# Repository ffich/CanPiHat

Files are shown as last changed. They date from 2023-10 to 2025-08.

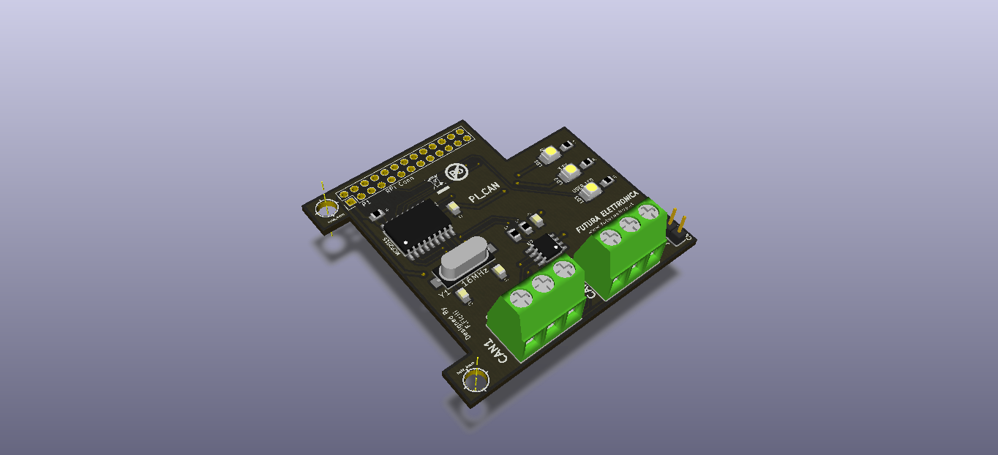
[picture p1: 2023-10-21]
50_3D/CanPi.png

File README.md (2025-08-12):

# 🐍🔌 CanPiHat — CAN Bus HAT for Raspberry Pi

A rugged **CAN-Bus HAT** for the **Raspberry Pi**, powered by the **Microchip MCP2515** CAN controller 🧠 and **MCP2551** high-speed transceiver. Perfect for automotive 🚗, industrial 🏭, and robotics 🤖 CAN applications.

---

## 📡 What is CAN Bus?

**CAN (Controller Area Network)** is a **robust, differential two-wire protocol** designed for reliable, real-time communication between multiple devices (ECUs).  

### ✨ Why CAN is Awesome:
- 🛡 **Reliable** — Automatic error detection, re-transmission & priority handling  
- 📏 **Efficient** — Reduces wiring complexity with a single shared bus  
- 🌍 **Versatile** — Used in cars 🚗, factories 🏭, robots 🤖, and building automation 🏢  

---

## 🛠 Features of CanPiHat

| Icon | Feature |
|---|---|
| 🧠 | **MCP2515** — Stand-alone CAN 2.0B controller with SPI interface (up to 1 Mbps) |
| ⚡ | **MCP2551** — High-speed CAN transceiver for physical layer communication |
| 🍓 | **Pi HAT Form Factor** — Plugs directly into Raspberry Pi’s 40-pin header |
| 🔌 | **Plug & Play** — Just enable SPI and start sending/receiving CAN frames |



---

## 🚀 Why You’ll Love It

- 🛠 **Simple Setup** — Minimal wiring, quick configuration  
- 🎯 **Proven Hardware** — Trusted Microchip CAN ICs  
- 🔄 **Flexible Applications** — From OBD2 logging to factory automation  
- 📡 **SocketCAN Compatible** — Works with `can-utils` and Python CAN libraries  

---

## ⚙ Getting Started

1. 🍓 **Stack** the HAT onto your Raspberry Pi  
2. 🔌 **Connect** CAN_H & CAN_L to your network  
3. 🖥 **Enable** SPI via `raspi-config`  
4. 📦 **Install** can-utils:  
  `sudo apt install can-utils`
5. ⚡ Bring up the CAN interface:
  `sudo ip link set can0 up type can bitrate 500000`
7. 📡 Communicate:
  `cansend can0 123#DEADBEEF`
  `candump can0`

---

## 💡 Applications
Area	Examples
🚗 Automotive	OBD2 data logging, ECU communication
🏭 Industrial	Motor drives, PLC networking
🤖 Robotics	Multi-node sensor & actuator control
🏢 Automation	Building CAN-based sensors & lighting

---

## 🏆 Summary
The 🐍🔌 CanPiHat turns your Raspberry Pi into a CAN bus powerhouse — ideal for diagnostics, data logging, and embedded networking.
With MCP2515 + MCP2551 under the hood, you get rock-solid performance in a compact, plug-and-play package.

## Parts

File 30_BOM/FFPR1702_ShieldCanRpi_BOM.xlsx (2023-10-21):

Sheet: Cover
Project Name | Date | Version Major | Version Minor
FFPR1701 - ShieldCanRpi | 29/10/2017 | 1 | 0
Description
Shield CAN RPI BOM | Bill of material for project FFPR1701 - ShieldCanRpi
Change Log
Author | Date | Version Major | Version Minor | Change
Francesco Ficili | 29/10/2017 | 1 | 0 | First release.

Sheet: Bill Of Material
BOM
Reference | Value | Quantity | Description | Package | Supplier | Supplier Code | Unit Price | Total Price | Notes
C1 | 100n | 1 | SMD Capacitor | SMD 0805 |  |  |  | 0.0000
C2,C3 | 22pF | 2 | SMD Capacitor | SMD 0805 |  |  |  | 0.0000
C4 | 100n | 1 | SMD Capacitor | SMD 0805 |  |  |  | 0.0000
J1 | CAN1 | 1 | Terminal Block 3P | NA | Farnell | 9632980 | 0.6760 | 0.6760
J2 | CAN2 | 1 | Terminal Block 3P | NA | Farnell | 9632980 | 0.6760 | 0.6760
JP1 | Term | 1 | Jumper | Header 2x1 |  |  |  | 0.0000
LD1 | LED1 | 1 | SMD LED Rosso | PLCC | Farnell | 1649010 | 0.2000 | 0.2000
LD2 | LED2 | 1 | SMD LED Verde | PLCC | Farnell | 1649006 | 0.2100 | 0.2100
LD3 | LED3 | 1 | SMD LED Verde | PLCC | Farnell | 1649006 | 0.2100 | 0.2100
P1 | RPI Conn | 1 | RPI Connector |  | Robot Italy | 807887 | 2.6200 | 2.6200 | Expensive, try to find alternative. Ask to Boris.
R1 | 4,7k | 1 | SMD Resistor | SMD 0805 |  |  |  | 0.0000
R2 | 10k | 1 | SMD Resistor | SMD 0805 |  |  |  | 0.0000
R3 | 15k | 1 | SMD Resistor | SMD 0805 |  |  |  | 0.0000
R4 | 120 | 1 | SMD Resistor | SMD 0805 |  |  |  | 0.0000
R5..R7 | 330 | 3 | SMD Resistor | SMD 0805 |  |  |  | 0.0000
U1 | MCP2515 | 1 | CAN Controller | SOIC18 | Farnell | 1292239 | 1.7000 | 1.7000
U2 | MCP2551 | 1 | CAN Transceiver | SOIC8 | Farnell | 1467746 | 1.0800 | 1.0800
Y1 | 16MHz | 1 | Crystal | HC49SM | Farnell | 1667012 | 0.7000 | 0.7000
Total: | 8.07
Total + VAT | 9.92856

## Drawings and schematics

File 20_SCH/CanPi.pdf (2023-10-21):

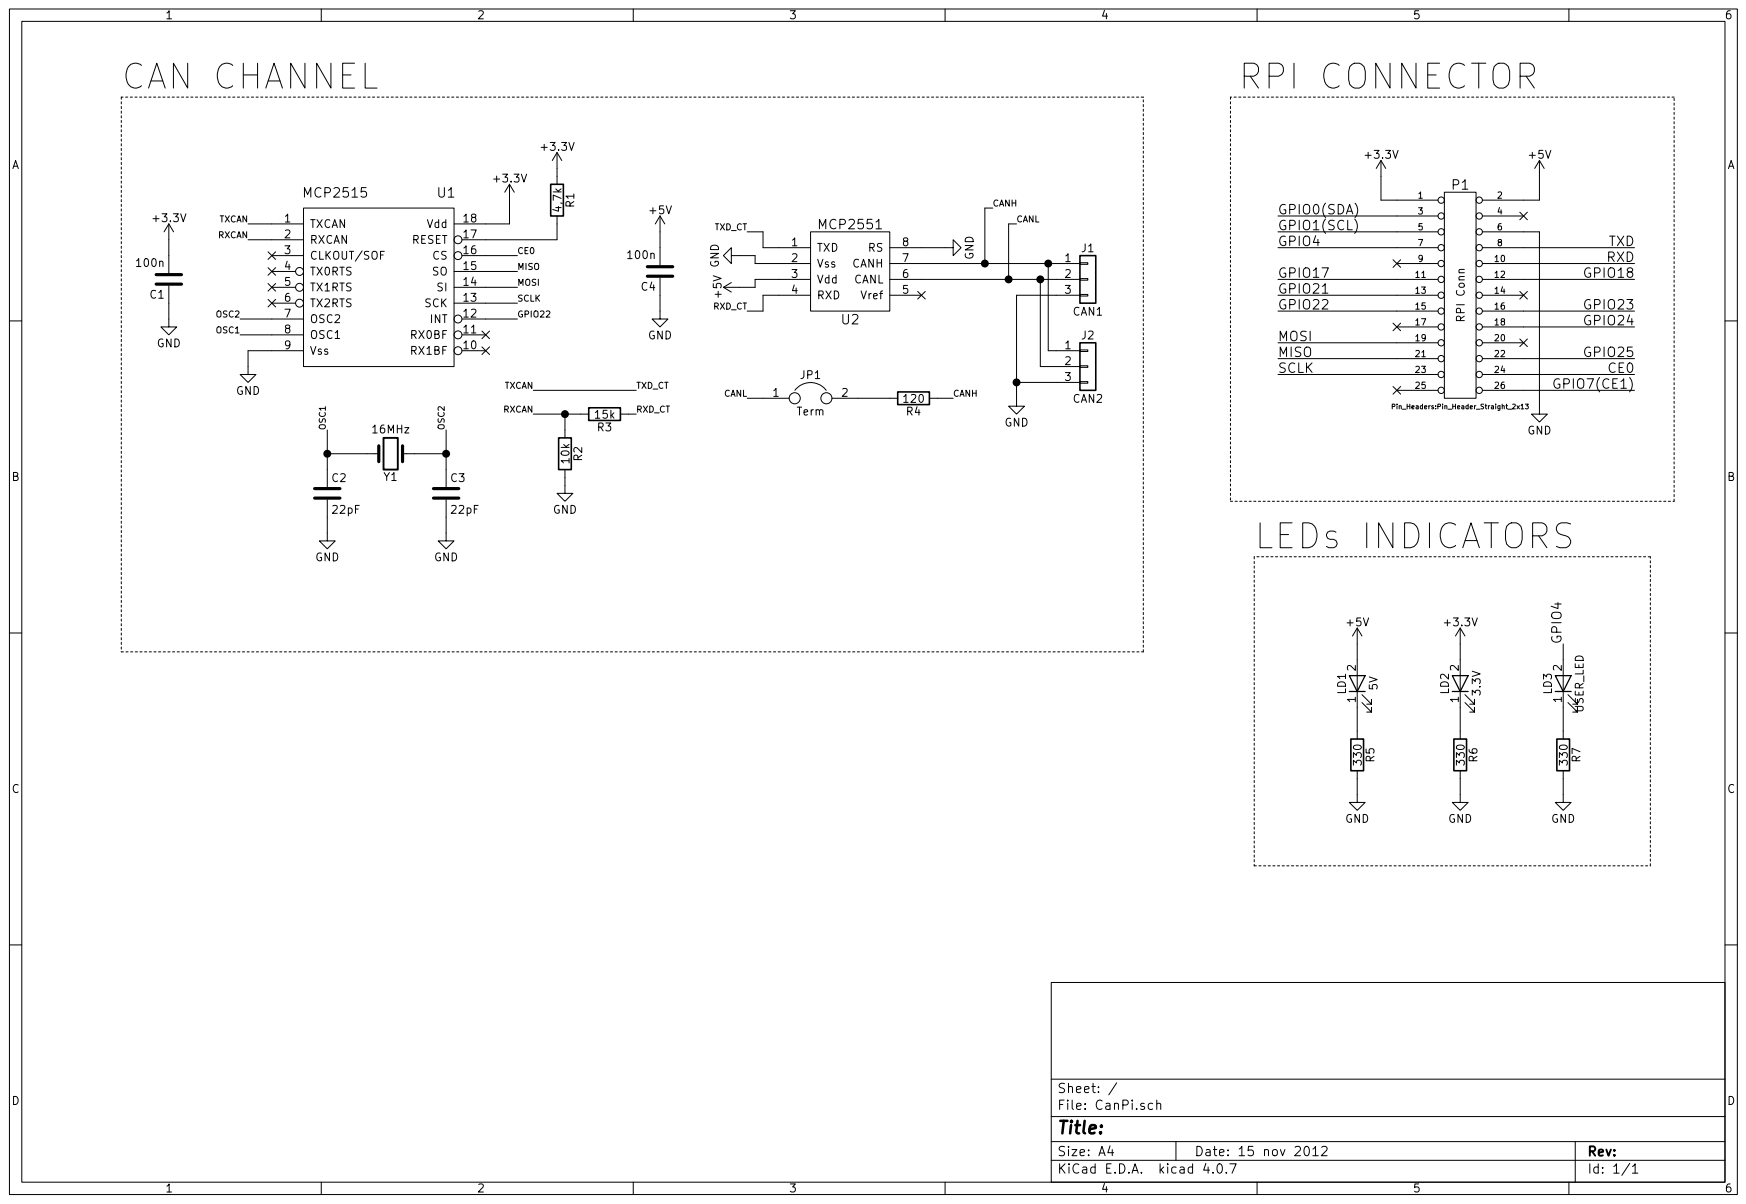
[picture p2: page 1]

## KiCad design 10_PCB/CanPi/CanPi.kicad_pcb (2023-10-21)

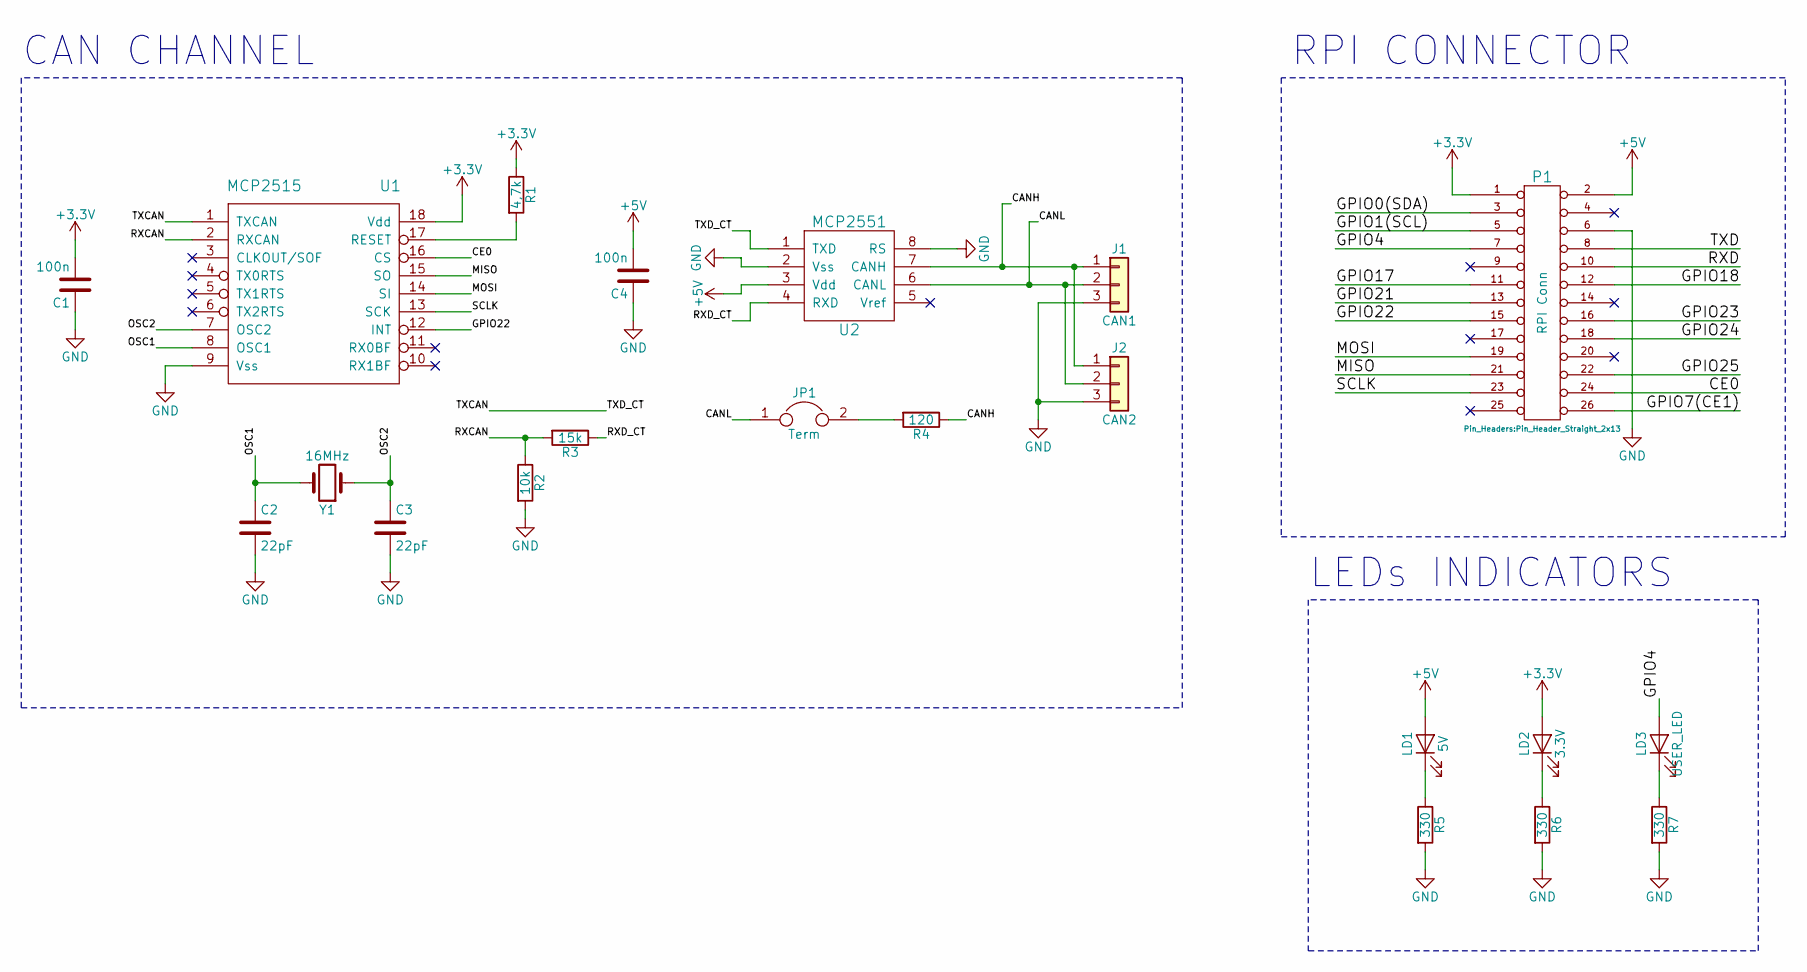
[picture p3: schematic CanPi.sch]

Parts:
C1, C4: 100n; c_0805
C2, C3: 22pF; c_0805
J1: CAN1; mkds_1,5-3
J2: CAN2; mkds_1,5-3
JP1: Term; pin_strip_2
LD1: 5V; Led_PLCC2_3528
LD2: 3.3V; Led_PLCC2_3528
LD3: USER_LED; Led_PLCC2_3528
P1: RPI Conn; Pin_Header_Straight_2x13
R1: 4,7k; r_0805
R2: 10k; r_0805
R3: 15k; r_0805
R4: 120; r_0805
R5, R6, R7: 330; r_0805
U1: MCP2515; soic-18
U2: MCP2551; so-8
Y1: 16MHz; crystal_hc-49%2fsmd

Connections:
+3V3: C1.2, LD2.2 (A), P1.1, R1.1, U1.18 (Vdd)
+5V: C4.2, LD1.2 (A), P1.2, U2.3 (Vdd)
/CANH: J1.1, J2.1, R4.1, U2.7 (CANH)
/CANL: J1.2, J2.2, JP1.1, U2.6 (CANL)
/CE0: P1.24 (P20), U1.16 (CS)
/GPIO0(SDA): P1.3
/GPIO1(SCL): P1.5
/GPIO4: LD3.2 (A), P1.7
/GPIO7(CE1): P1.26 (P22)
/GPIO17: P1.11
/GPIO18: P1.12
/GPIO21: P1.13
/GPIO22: P1.15, U1.12 (INT)
/GPIO23: P1.16
/GPIO24: P1.18
/GPIO25: P1.22
/MISO: P1.21, U1.15 (SO)
/MOSI: P1.19, U1.14 (SI)
/OSC1: C2.1, U1.8 (OSC1), Y1.2
/OSC2: C3.1, U1.7 (OSC2), Y1.1
/RXCAN: R2.1, R3.2, U1.2 (RXCAN)
/RXD: P1.10
/RXD_CT: R3.1, U2.4 (RXD)
/SCLK: P1.23, U1.13 (SCK)
/TXCAN: U1.1 (TXCAN), U2.1 (TXD)
/TXD: P1.8
GND: C1.1, C2.2, C3.2, C4.1, J1.3, J2.3, P1.6, R2.2, R5.2, R6.2, R7.2, U1.9 (Vss), U2.2 (Vss), U2.8 (RS)
unnamed: JP1.2, R4.2
unnamed: LD1.1 (K), R5.1
unnamed: LD2.1 (K), R6.1
unnamed: LD3.1 (K), R7.1
unnamed: R1.2, U1.17 (RESET)

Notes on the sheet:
RPI CONNECTOR
CAN CHANNEL
LEDs INDICATORS

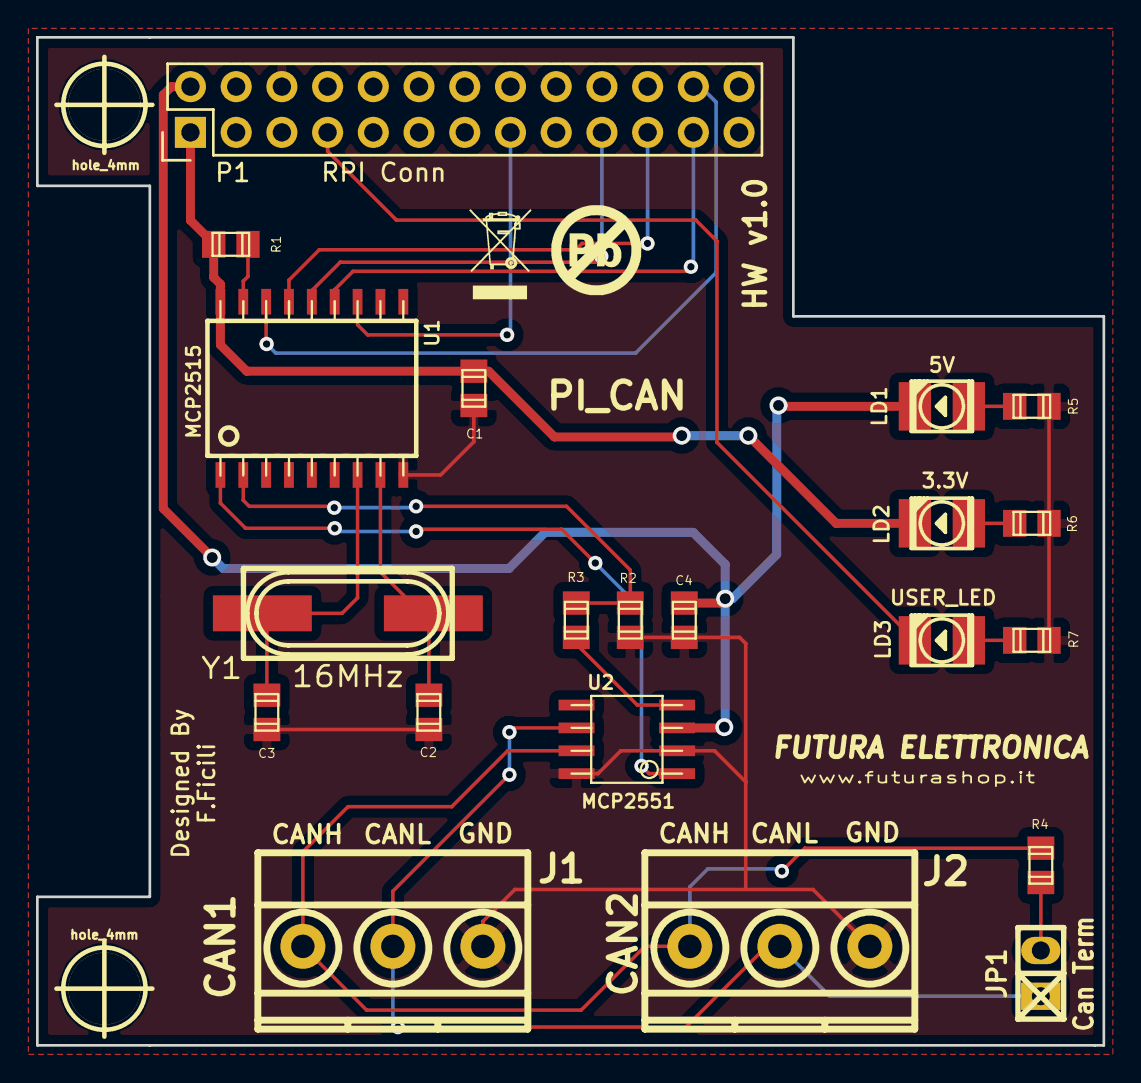
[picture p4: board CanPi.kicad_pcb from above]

Board: 2 copper layers, 59.2 x 56.0 mm, 23 parts (0 on the bottom side), 21 nets.

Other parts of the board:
hole_4mm, hole_4mm#2: hole_4mm
